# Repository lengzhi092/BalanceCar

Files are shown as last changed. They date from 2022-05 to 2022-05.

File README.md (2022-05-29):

# 双轮平衡车运动控制系统
## 硬件部分
* MCU:STM32F103C8T6
* 姿态采集:MPU6050
* 电机驱动:TB6612FNG

## 开发平台
* STM32CubeMX
* Keil MDK5

## 软件算法
* 卡尔曼滤波
* 串级PID控制
* 速度一阶低通滤波

## 实物展示

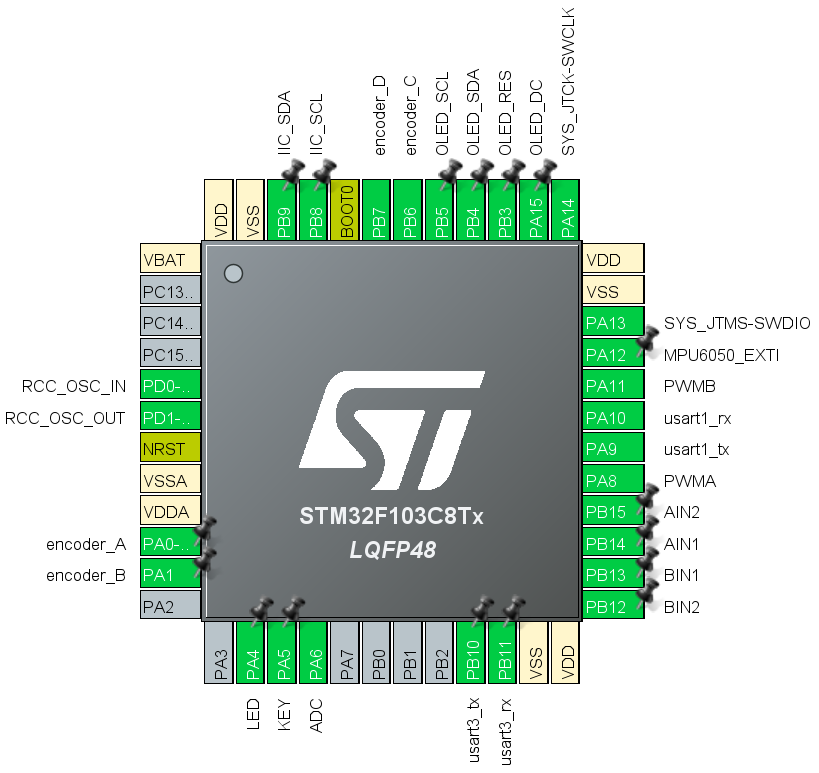
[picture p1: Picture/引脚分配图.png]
引脚分配图

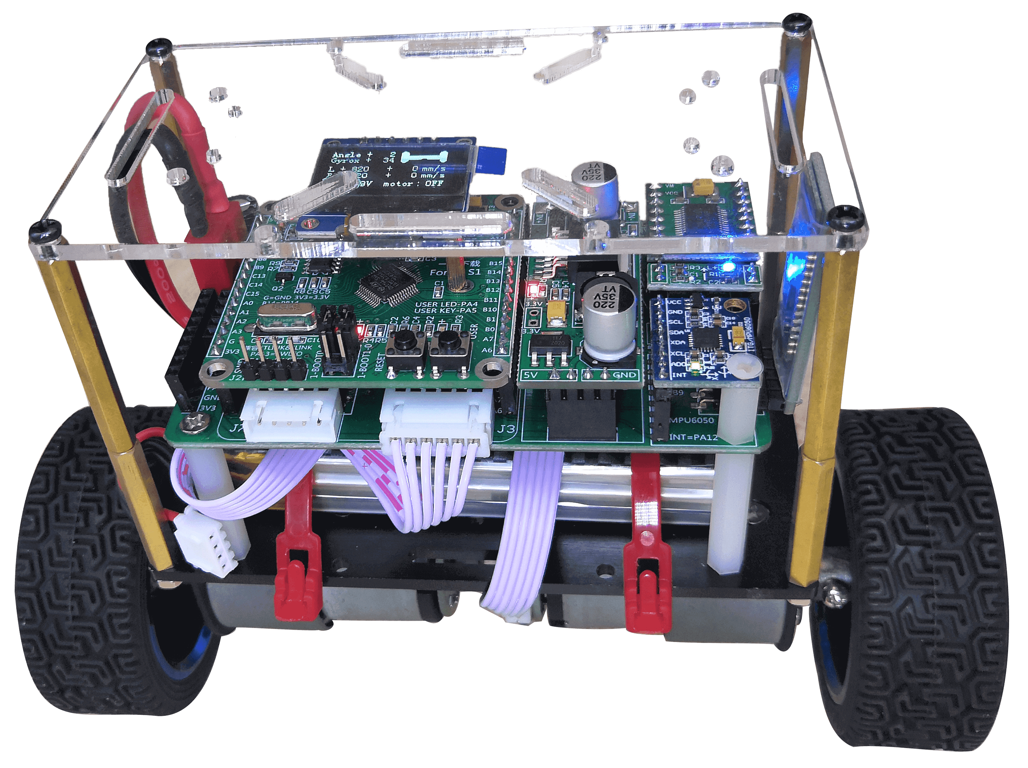
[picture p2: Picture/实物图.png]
车体

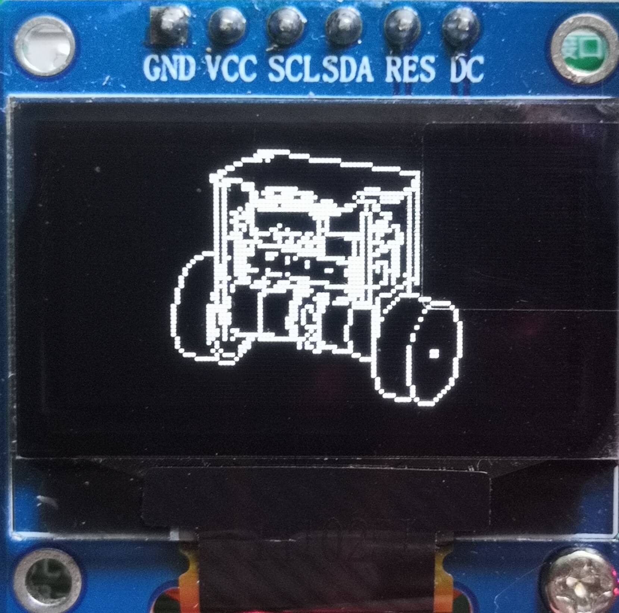
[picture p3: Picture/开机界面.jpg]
开机界面

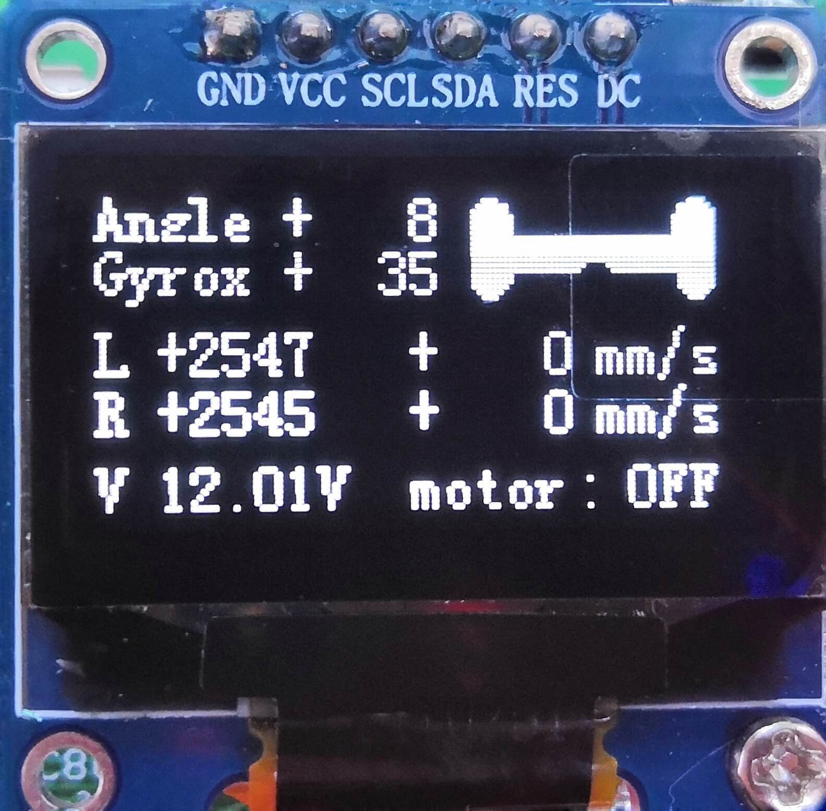
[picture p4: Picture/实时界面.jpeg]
实时界面

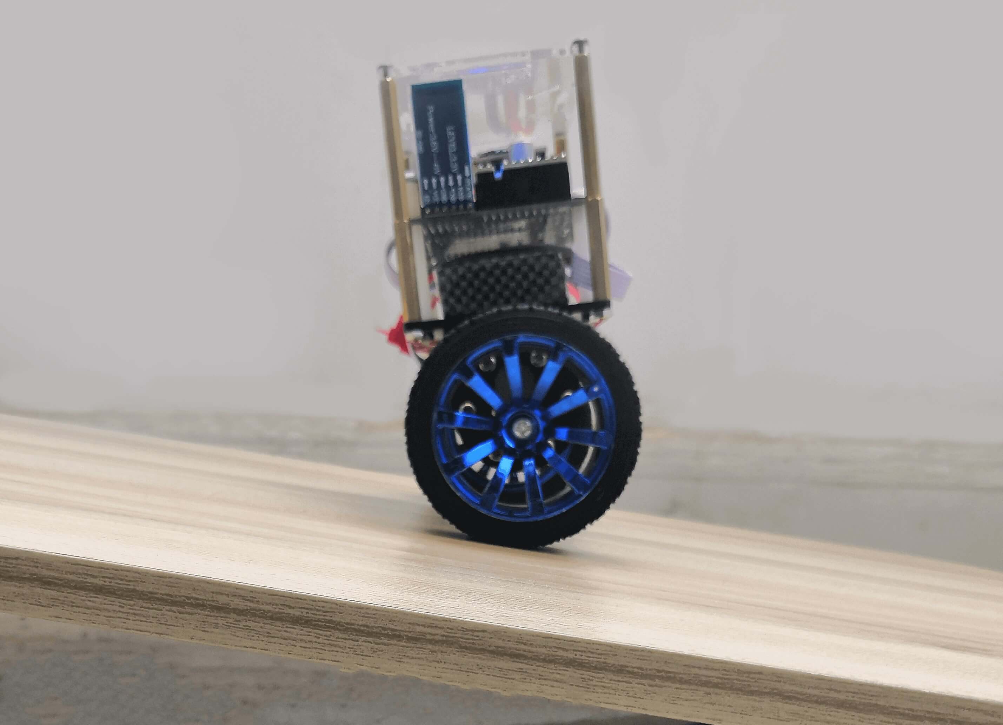
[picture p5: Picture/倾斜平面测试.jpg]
倾斜平面测试


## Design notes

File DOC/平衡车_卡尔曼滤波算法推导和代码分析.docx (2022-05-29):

状态方程： X_k =AX_(k-1) +BU_(k-1) +W_(k-1)

测量方程： Z_k =HX_k -V_k

U_(k-1) ：系统输入量

A、 B：系统参数矩阵

H：观测矩阵

W_(k-1) ：过程噪声矩阵，W~N(0,Q)，Q为过程噪声协方差矩阵

V_k ：观测噪声矩阵，V~N(0,R)，R为观测噪声协方差矩阵

## 一、根据状态方程计算先验估计

X_k^(-) =AX_(k-1) +BU_(k-1)

用陀螺仪计算的角度做估计值： X_k^(-) =Angle_k =Angle_(k-1) +(Gyro_(k-1) -Q_(bias) _(k-1) )dt+W_(k-1)

Q_bias_k =Q_bias_(k-1) +W_(k-1)

Q_bias：陀螺仪静态漂移，是一个变化的量，但是认为预测时现在的漂移跟上一时刻是相同的。

上面两个方程写成矩阵的形式，即得到状态方程：

X_k =[AngleQ_bias]_k =[1, -dt0, 1][AngleQ_bias]_(k-1) +[dt0]Gyro_(k-1) +[W_(k-1) W_(k-1) ]

用加速度分解得到的角度做测量值： Z_k =Accel=Angle_k +R ，写成矩阵形式，得到测量方程：

Z_k =[1, 0][AngleQ_bias]_k +R

将状态方程中的A、B代入上面红色公式，在程序中算出 Angle_k^(-) ，而 Q_bias_k^(-) 预测时认为不变。

## 二、计算先验估计误差协方差矩阵

P_K^(-) =AP_(k-1) A^T +Q

1.先分析过程噪声的协方差矩阵Q

Q=cov[AngleQ_bias]·dt=[cov(Angle,Angle), cov(Q_bias,Angle)cov(Angle,Q_bias), cov(Q_bias,Q_bias)]·dt

协方差知识：衡量两个变量的总体误差

cov(x,y)=1/N∑_(i=1)^n [x_i -E(x)][y_i -E(y)]

当 x、y 相互独立时， cov(x,y)=0

当 x=y 时，协方差又称方差： cov(x,x)=D(x)=1/N∑_(i=1)^n [x_i -E(x)]^2

Angle和Q_bias 相互独立，所以 Q=[D(Angle), 00, D(Q_bias)]·dt

在程序中 D(Angle)=Q_angle=0.001 ， D(Q_(bias) )=Q_gyro=0.003

2.计算先验估计误差协方差矩阵 P_k^(-) ，在程序中 P_k^(-) =[PP_00 , PP_01 PP_10 , PP_11 ]_k^(-) ，代入上方红色公式：

P_k^(-) =[1, -dt0, 1][PP_00 , PP_01 PP_10 , PP_11 ]_(k-1) [1, 0-dt, 1]+[D(Angle), 00, D(Q_bias)]·dt =[PP_00 -PP_10 dt-PP_10 dt+PP_11 (dt)^2 +D(Angle)dt, PP_01 -PP_11 dtPP_10 -PP_11 dt, PP_11 +D(Q_(bias) )dt]_(k-1) =[PP_00 , PP_01 PP_10 , PP_11 ]_(k-1) +[-PP_10 -PP_01 +PP_11 dt+D(Angle), -PP_11 -PP_11 , D(Q_bias)]_(k-1) ·dt

PP_11 (dt)^2 这一项比较小，计算时忽略，然后就是在程序中代公式了，计算出 PP_k^(-) 的四个值。

## 三、计算卡尔曼增益

K_k =P_k^(-) H^T (HP_k^(-) H^T +R)^(-1)

由测量方程知： H=[1, 0] ，先算分母

HP_k^(-) H^T +R=[1, 0][PP_00 , PP_01 PP_10 , PP_11 ]_k^(-) [10]+R=PP_00 _k^(-) +R

整体 K_k =[PP_00 , PP_01 PP_10 , PP_11 ]_k [10]×1/(PP_00 _k^(-) +R)=[PP_00 PP_10 ]×1/(PP_00 _k^(-) +R)=[K_0K_1]

在程序中观测噪声 R=R_angle=0.5 ，代公式计算出 K_0 和 K_1 。

## 四、更新后验估计

X_k =X_K^(-) +K_k (Z_k -HX_K^(-) )

先算括号里的： Z_k -HX_K^(-) =Accel-[1, 0][AngleQ_(bias) ]_k^(-) =Accel-Angle_k^(-)

整体 X_k =[AngleQ_bias]_k =[AngleQ_bias]_k^(-) +[K_1 K_0 ](Accel-Angle_k^(-) )

在程序中算出 Angle_k 和 Q_bias_k

## 五、更新后验估计误差协方差矩阵

P_k =(I-K_k H)P_K^(-)

I 为单位矩阵，代公式 P_k =[[1, 00, 1]-[K_0K_1][1, 0]][PP_00 , PP_01 PP_10 , PP_11 ]_k^(-) = [1-K_0, 0-K_1, 1][PP_00 , PP_01 PP_10 , PP_11 ]_k^(-) =[PP_00 -PP_00 K_0, PP_01 -PP_01 K_0-PP_00 K_1 +PP_10 , PP_01 K_1+PP_11 ]_k^(-)

=[PP_00 , PP_01 PP_10 , PP_11 ]_k^(-) +[-PP_00 K_0, -PP_01 K_0-PP_00 K_1, -PP_01 K_1]_k^(-)

在程序中代公式更新 PP_k 的四个值。

## 程序设计

/**

****************************************************************************

*@brief 获取x轴角度简易卡尔曼滤波

*@param Accel：加速度计获取的角度、Gyro：陀螺仪获取的角速度

*@retval x轴角度

****************************************************************************

*/

float dt=0.005; //每5ms进行一次滤波

float Kalman_Filter_x(float Accel,float Gyro)

{

// static float angle_dot; 角度微分=角速度，本系统用不到

static float angle;

float Q_angle=0.001; // 过程噪声的协方差

float Q_gyro=0.003; //过程噪声的协方差

float R_angle=0.5; //测量噪声的协方差,值越大表示越不信任测量值

char C_0 = 1; //在此程序显得多余

static float Q_bias, Angle_err; //陀螺仪静态漂移

static float PCt_0, PCt_1, E; //E:卡尔曼增益分母

static float K_0, K_1, t_0, t_1;

static float Pdot[4] ={0,0,0,0};

static float PP[2][2] = { { 1, 0 },{ 0, 1 } }; //PP为协方差矩阵Pk-的先验估计值

/************* 角度先验估计 ****************///Xk = A Xk-1 + B Uk-1

angle += (Gyro - Q_bias) * dt;

/************* 先验估计误差协方差 ****************///Pk- =A Pk-1 AT + Q

Pdot[0] = Q_angle - PP[0][1] - PP[1][0];

Pdot[1] = -PP[1][1];

Pdot[2] = -PP[1][1];

Pdot[3] = Q_gyro;

PP[0][0] += Pdot[0] * dt;

PP[0][1] += Pdot[1] * dt;

PP[1][0] += Pdot[2] * dt;

PP[1][1] += Pdot[3] * dt;

/************* 计算卡尔曼增益 ****************///Kk = Pk- HT / (H Pk- HT + R)

PCt_0 = C_0 * PP[0][0]; //显得多余

PCt_1 = C_0 * PP[1][0]; //显得多余

E = R_angle + C_0 * PCt_0; //求卡尔曼增益分母，直接E = R_angle + PP[0][0]就行

K_0 = PCt_0 / E; //计算卡尔曼增益，为两行一列的矩阵

K_1 = PCt_1 / E;

/************* 角度后验估计 ****************///Xk = Xk- + Kk (Zk - H Xk-)

Angle_err = Accel - angle; //(Zk - H Xk-)

angle += K_0 * Angle_err; //后验估计

Q_bias += K_1 * Angle_err; //后验估计

// angle_dot = Gyro - Q_bias; //输出值(后验估计)的微分=角速度

/************* 更新协方差矩阵 ****************///Pk = (I - Kk H) Pk-

t_0 = PCt_0;

t_1 = C_0 * PP[0][1];

PP[0][0] -= K_0 * t_0; //后验估计误差协方差

PP[0][1] -= K_0 * t_1;

PP[1][0] -= K_1 * t_0;

PP[1][1] -= K_1 * t_1;

return angle;

}

WRITE BY LENGZHI

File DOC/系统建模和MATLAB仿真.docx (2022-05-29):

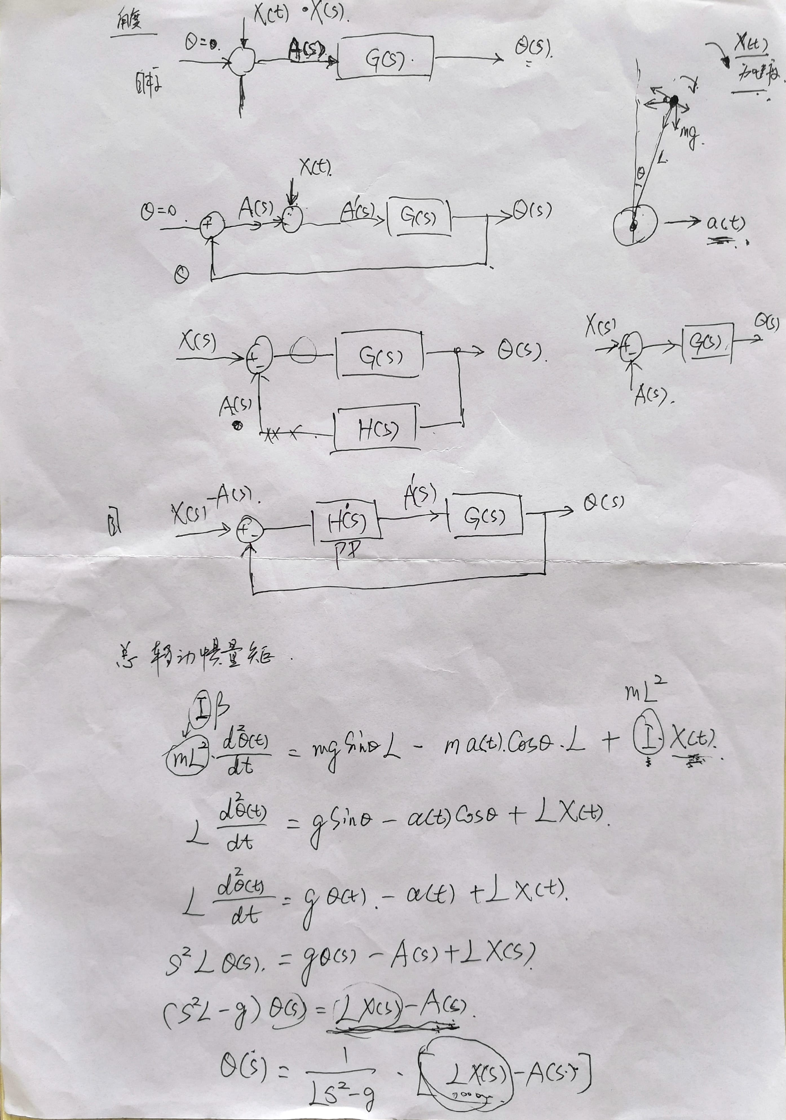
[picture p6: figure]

# 传递函数建立

模型分析主要有两种方法，一种是拉格朗日(Lagrange)分析法，该方法引用广义坐标，降低了分析对象的难度，但是理解上较为困难。另一种是牛顿欧拉方程法(Newton-Euler)，它的优点是根据我们学过的牛顿三大定律进行分析，模型表达式也代表确定的物理含义，建模过程更加通俗易懂，并且其计算相对简便，对于后期的控制算法设计也有一定的简化。

双轮平衡车模型类似一级倒立摆，我们将并行的双轮设定在一个点上，同时忽略其转向控制，有倒下趋势的倒立摆为非惯性系统，，切换参照物，不再以地面为参照，以车轮中线为原点O，向前为x轴正方向，竖直向上为y轴正方向，建立二维的平衡车的倒立摆模型

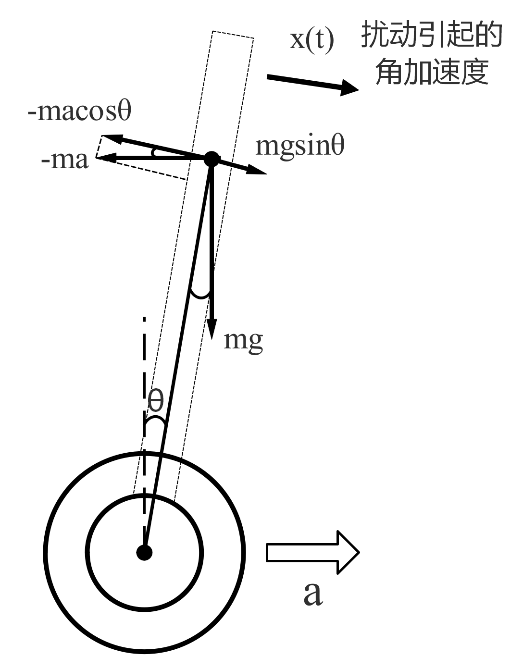
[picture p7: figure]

在非惯性坐标系下，对模型进行受力分析，设小车质量为m，车轮向前加速后产生一个向后的“惯性力”，提供车体回复力的一部分，它的大小和车轮向前施加的力相等，与车轮加速的方向相反

F_惯 =-macosθ

假设平衡车的重心高度为L，转动惯量矩 =FL=Ιβ ，Ι =mL^2 ，β为角加速度

系统转动惯量矩平衡方程可以表示为:

mL^2 (ⅆ^2 θ(t))/(ⅆt^2)=mgsin[θ(t)]L-ma(t)cos[θ(t)]L+mL^2 x(t)

线性化处理，当θ很小时 sinθ=θ , cosθ=1 ，可以将运动微分方程简化为

L(ⅆ^2 θ(t))/(ⅆt^2)=gθ(t)-a(t)+Lx(t)

以 Lx(t) 和车轮的加速度 a(t) 之差为输入, 倾角 θ(t) 为输出的开环传递函数为：

H(s)=(Θ(s))/(LX(s)-A(s))=1/(Ls^2 -g)

此时平衡车系统有两个闭环极点： s_p =±√((g-1)/L) ，分别位于位于s平面的左半平面和右半平面，根据 Nyquist 判据判断出该系统不稳定，

引入PD控制，新的系统开环传递函数为：

H(s)=(Θ(s))/(LX(s)-A(s))=(k_p +k_d s)/(Ls^2 -g)

对应的闭环传递函数为：

H(s)=(Θ(s))/(LX(s)-A(s))=(k_p +k_d s)/(Ls^2 +k_d s+k_p -g)

这时系统有两闭环极点， S_P =(-k_d ±√(k_d^2 +4L(k_p -g)))/(-2L) 根据Nyquist判据,要使系统稳定，只需两极点都处在s平面的左半平面，即要求 k_p >g ， k_d >0

1.在matlab中进行系统建模，在不加入控制量的情况下，输出其零输入响应图，印证了此系统为自然不稳定体的结论。

2.在模型中增设控制量参数，通过冲激响应验证其在控制下能够保持平衡稳定。

3.利用连续的阶跃响应验证了在加入持续的控制量参数情况下，系统会随控制量的增加调整系统的姿态，并且在持续加入控制量时维持此种姿态。

通过以上仿真实验，验证了此系统下的动态平衡，同时也为后续的软件设计控制算法及其控制量参数调整的方向上给予了一定的指导经验。

# Simulink模型搭建

## Transfer function 传递函数

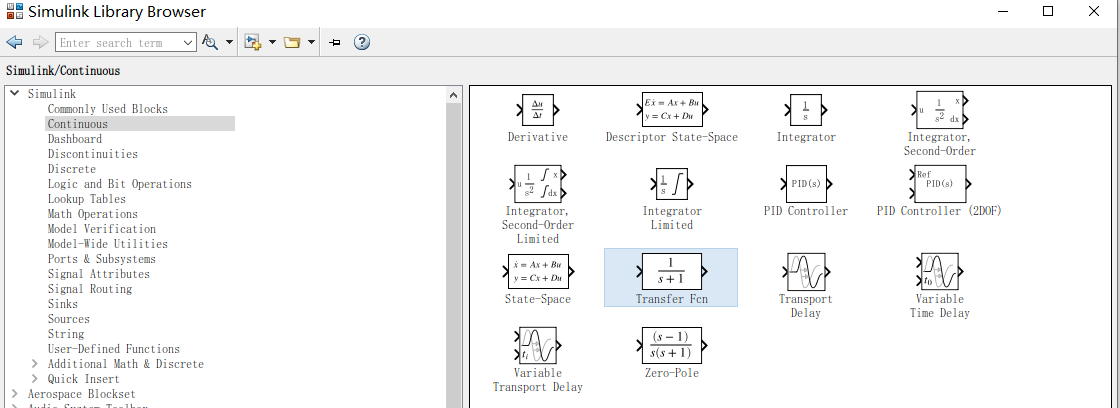
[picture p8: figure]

## Constant 常数

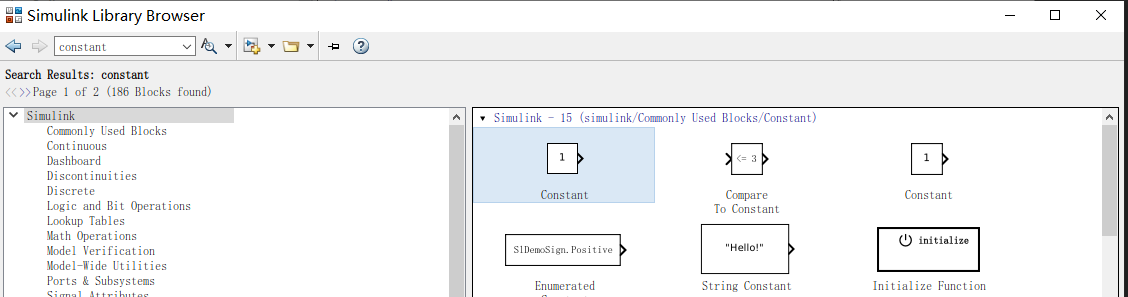
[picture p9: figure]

## Sum

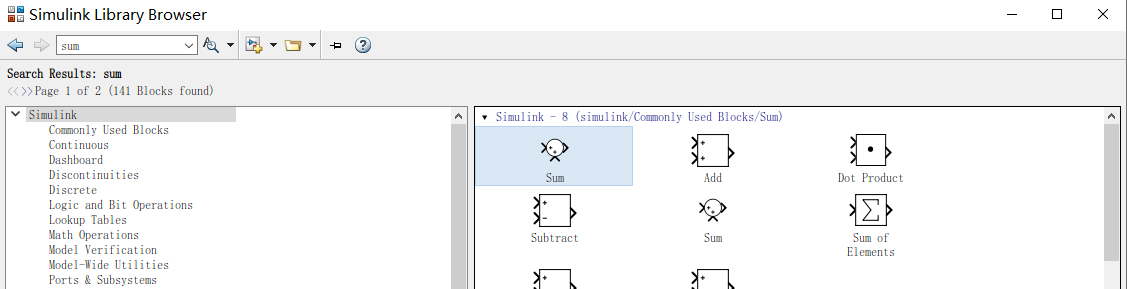
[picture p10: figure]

## pid

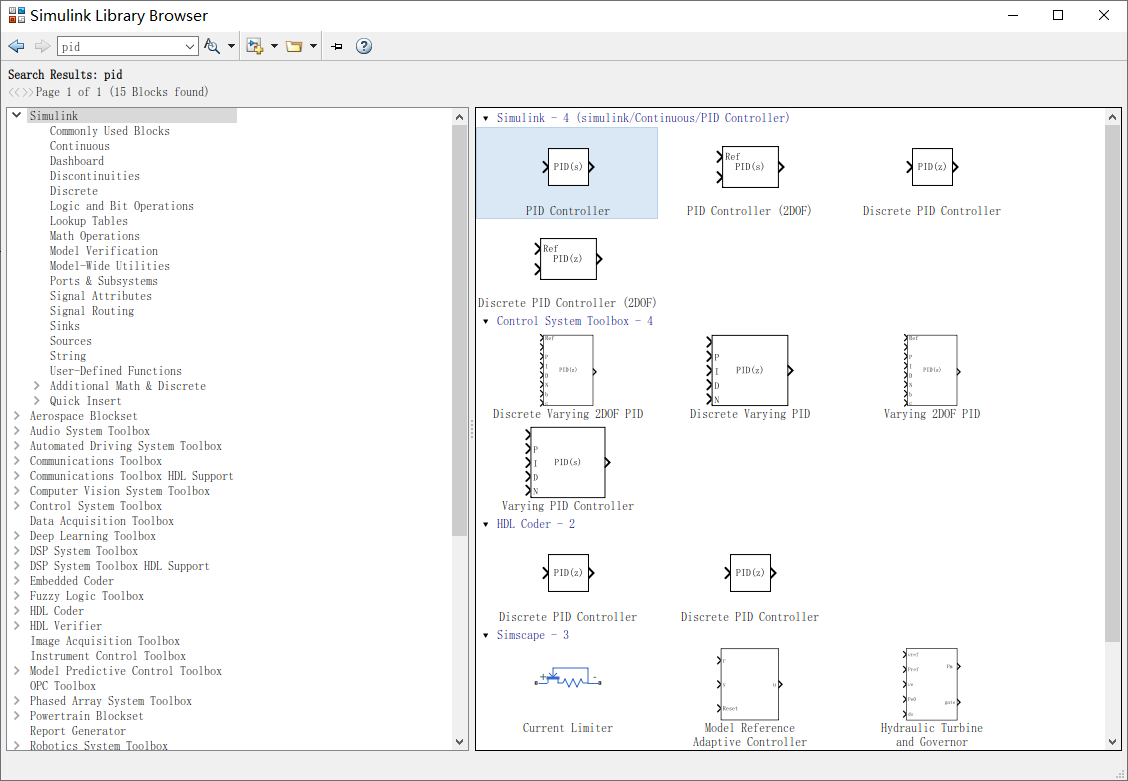
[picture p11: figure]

## Scope

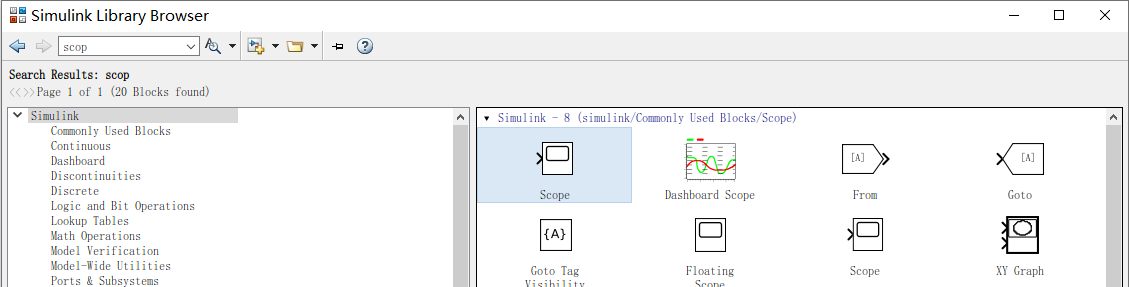
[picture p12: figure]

# 最终模型

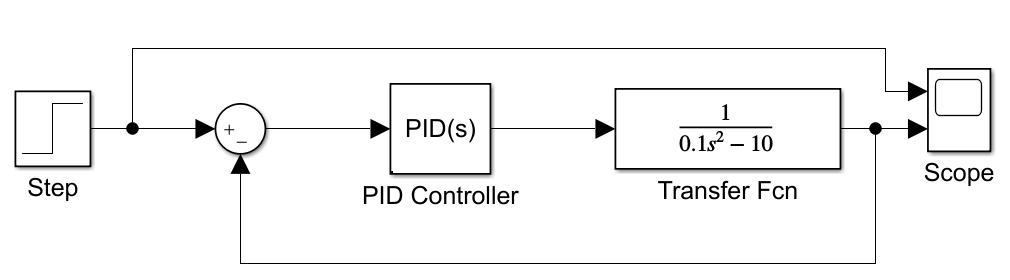
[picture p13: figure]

# 错误调参记录

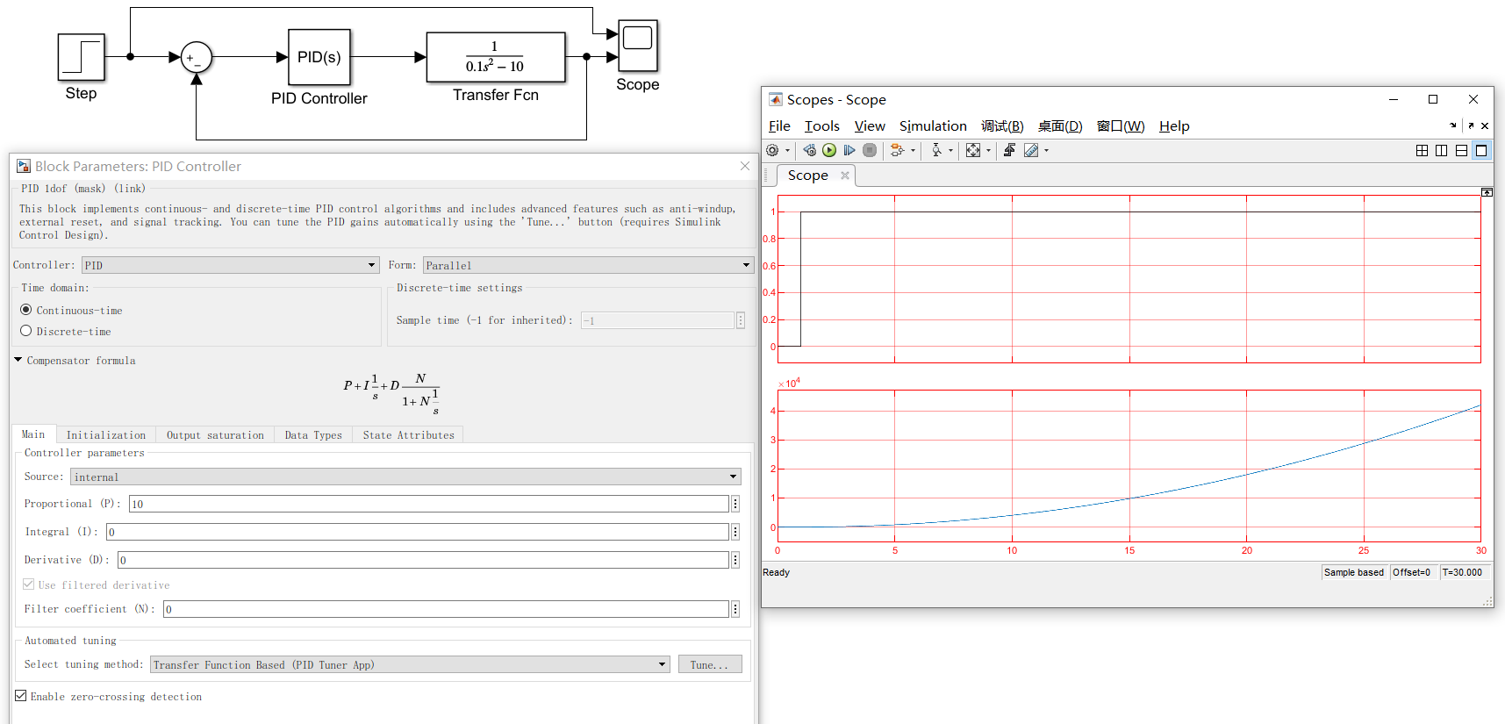
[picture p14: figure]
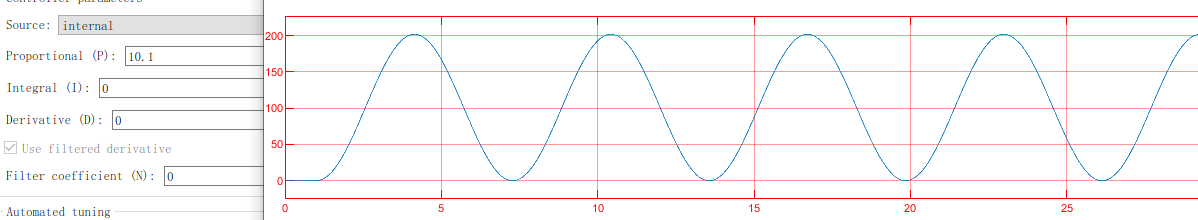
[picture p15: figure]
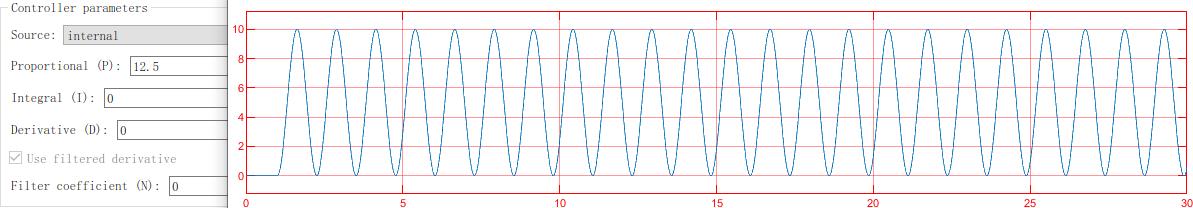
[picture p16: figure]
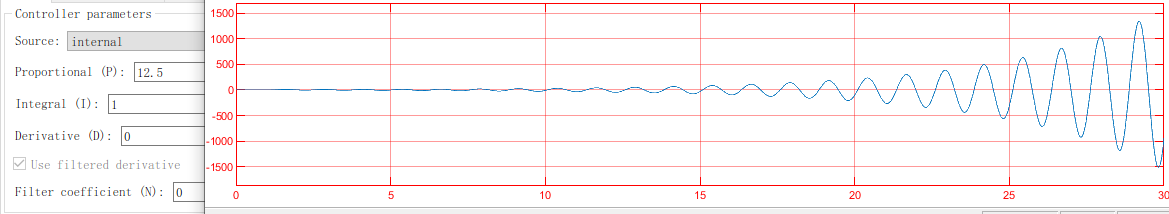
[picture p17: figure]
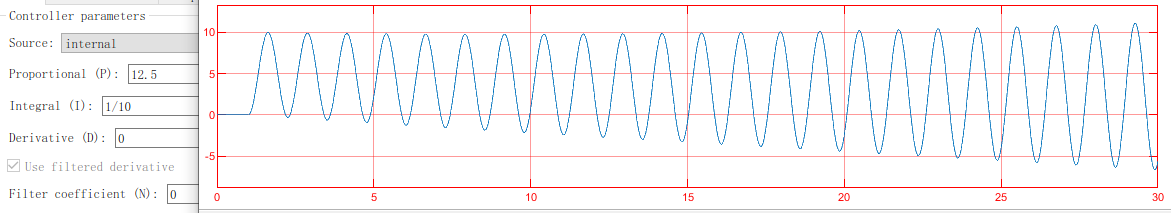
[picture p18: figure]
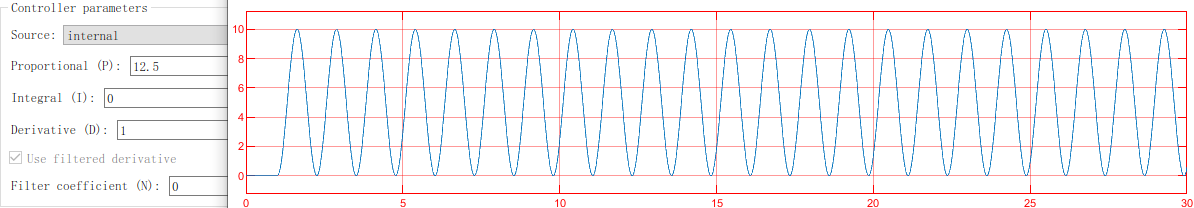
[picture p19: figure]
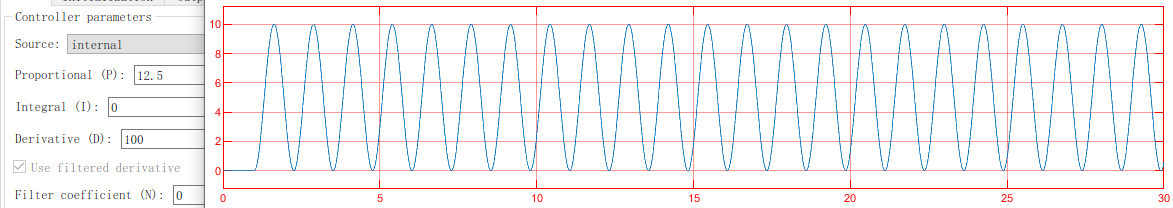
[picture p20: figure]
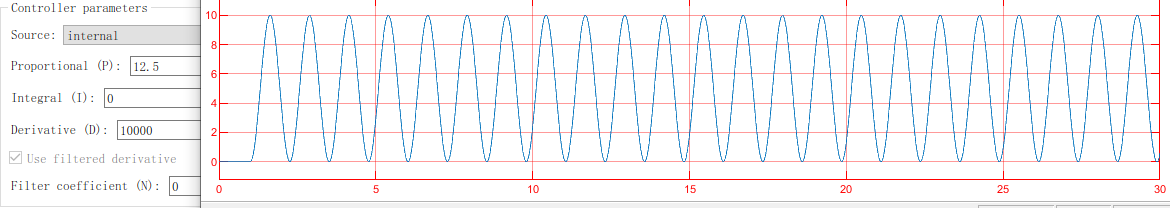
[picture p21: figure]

# 老师指导结果

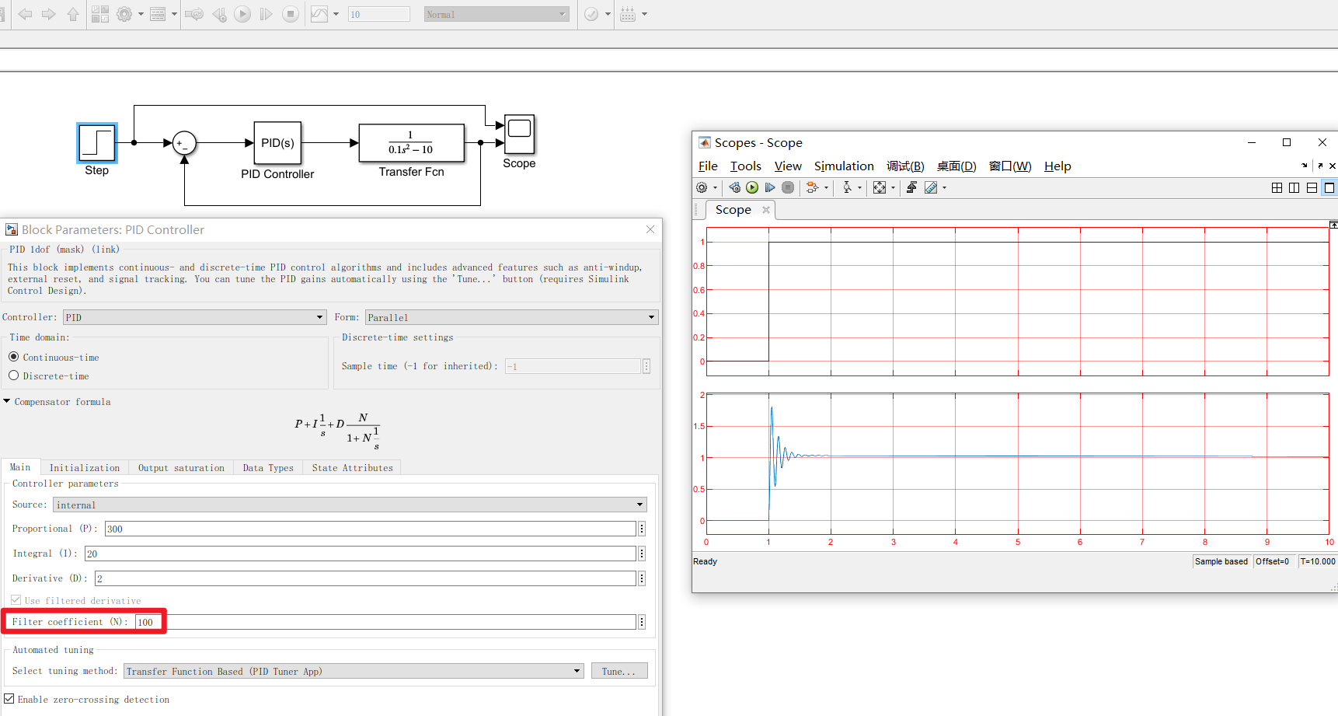
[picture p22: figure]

原因总结：调参不仅要调PID，根据实际情况，还要调filter coefficient（上图红框），因为误差e变化微弱的时候，如果D过大会产生过大的修正量，导致震动不但不减小反而扩大，滤波器的作用就是滤除高频修正

# 再次自主调参记录

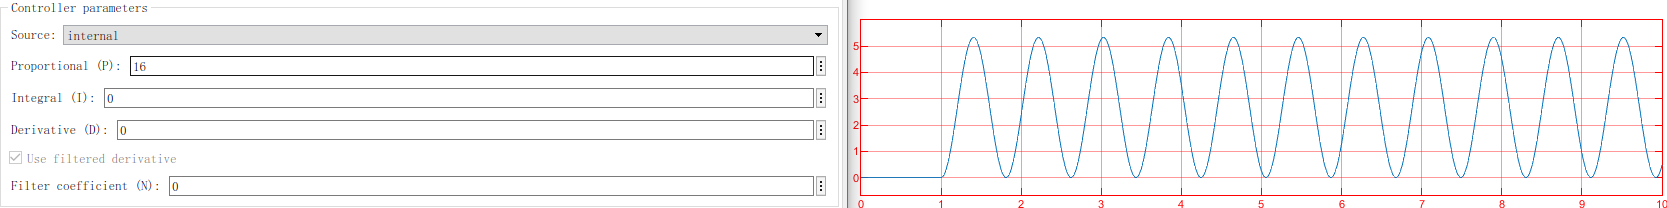
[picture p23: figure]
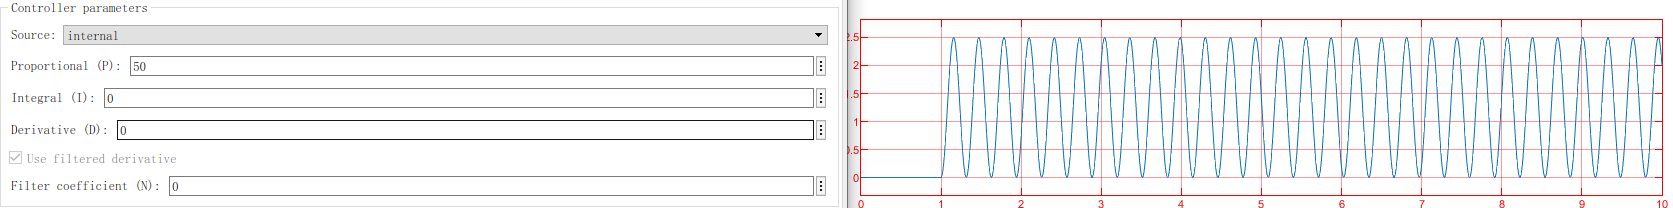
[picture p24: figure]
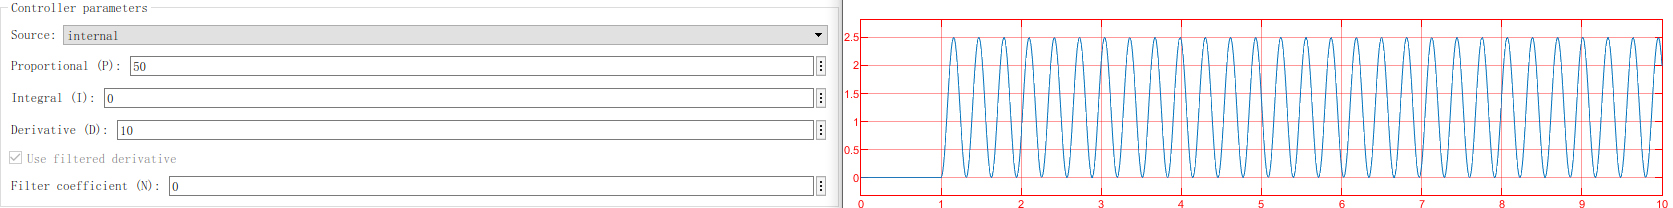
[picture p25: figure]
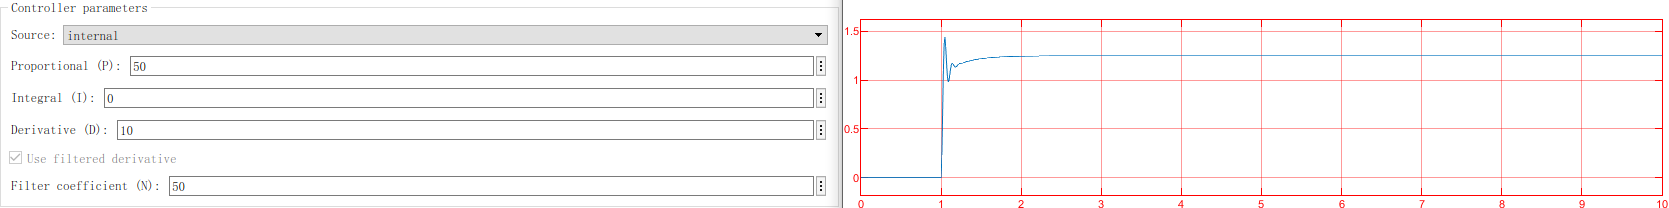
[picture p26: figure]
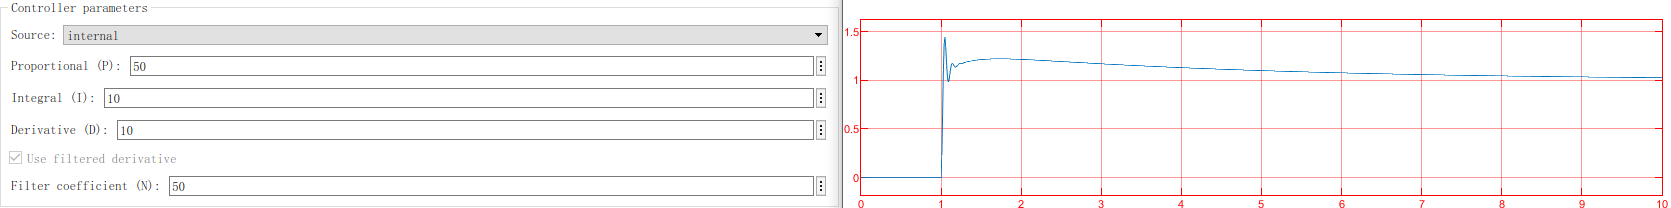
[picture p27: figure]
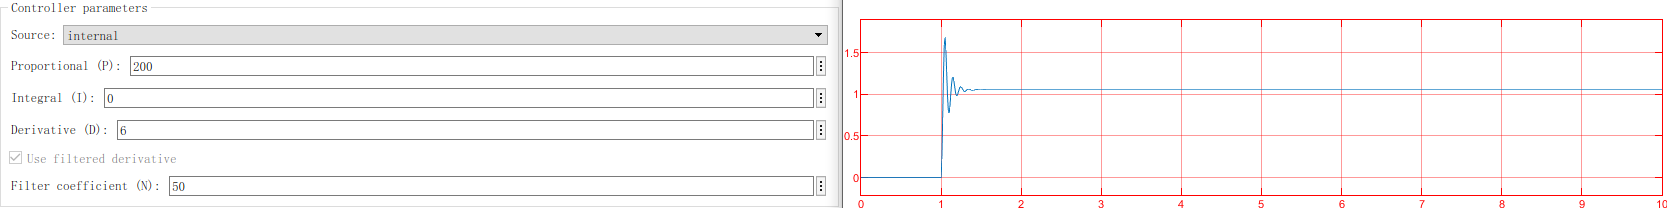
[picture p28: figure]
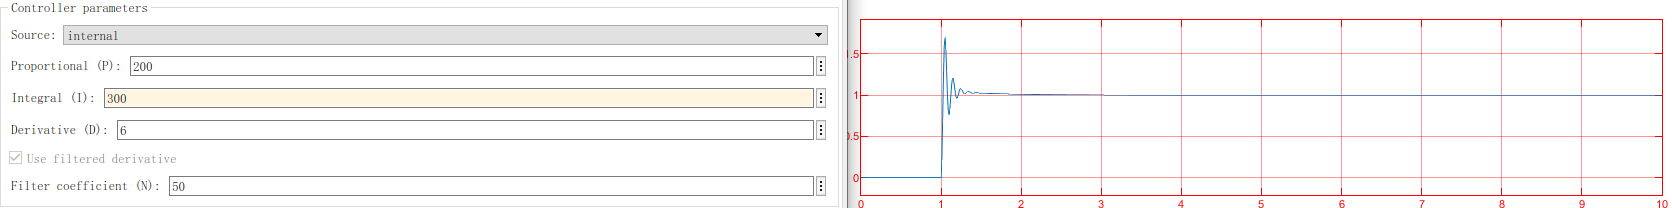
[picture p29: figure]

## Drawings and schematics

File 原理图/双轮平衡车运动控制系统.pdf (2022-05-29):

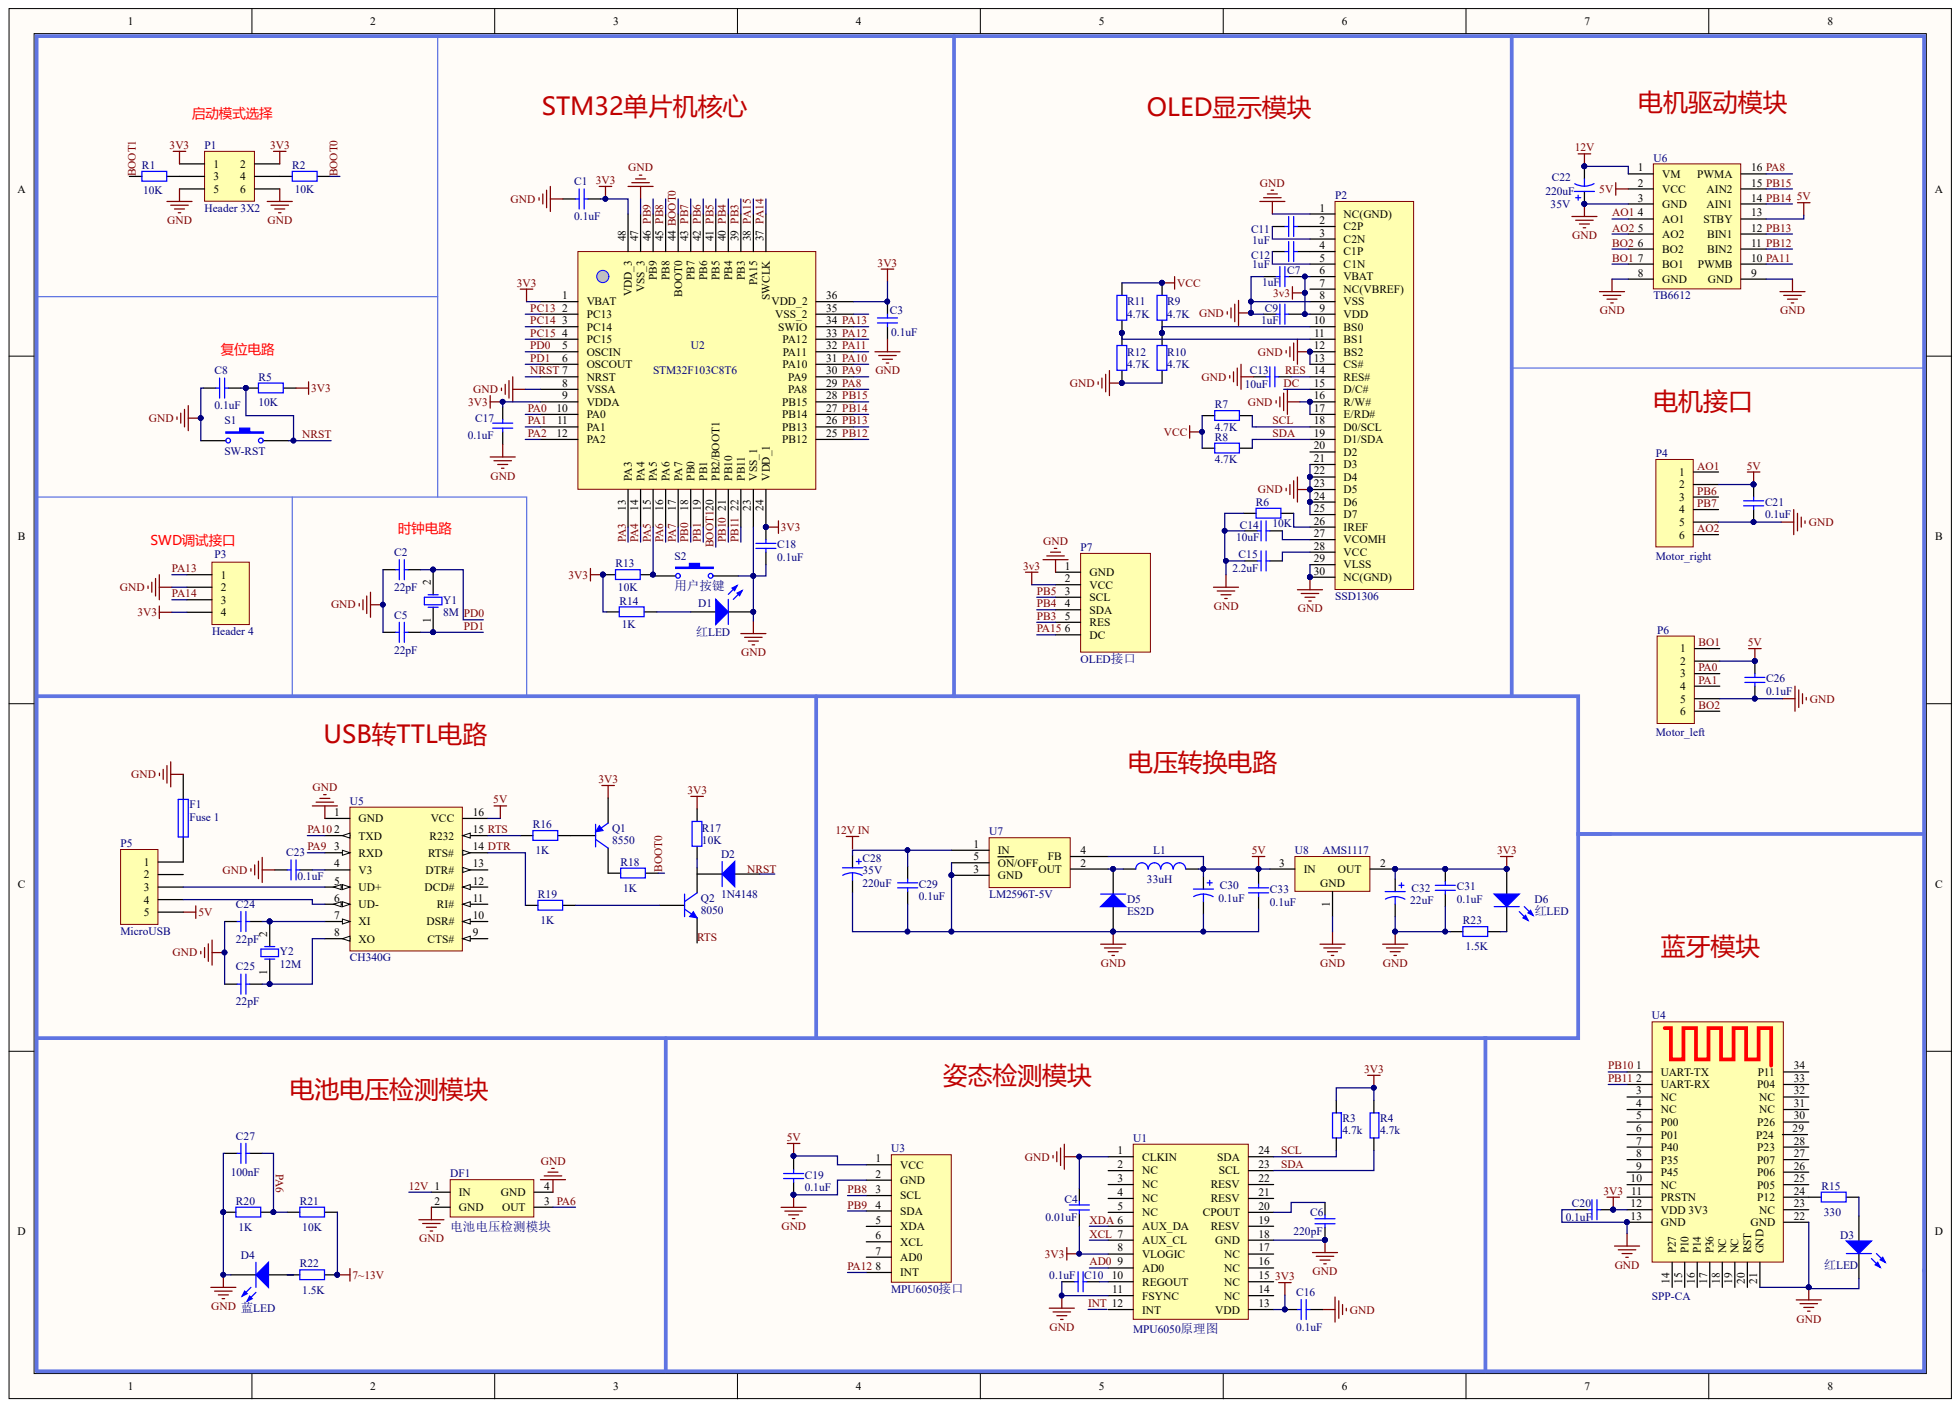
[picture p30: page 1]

GND 21 GND 22 NC 23 P12 24 P05 25 P06 26 P07 27 P23 28 P24 29 P26 30 NC 31 NC 32 P04 33 P11 34

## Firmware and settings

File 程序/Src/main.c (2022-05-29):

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
/* Includes ------------------------------------------------------------------*/
#include "main.h"
#include "adc.h"
#include "tim.h"
#include "usart.h"
#include "gpio.h"

/* USER CODE BEGIN Includes */
#include "sys.h"
/* USER CODE END Includes */

/* USER CODE BEGIN PTD */
float Angle_Balance,Gyro_Balance,Gyro_Turn; //平衡倾角 平衡陀螺仪 转向陀螺仪
float Velocity_Left,Velocity_Right; //车轮速度(mm/s)
int Temperature;    //温度变量
float Acceleration_Z;   //Z轴加速度计  
int Voltage;    //电池电压采样相关的变量
volatile u8 delay_flag,delay_50;    //提供延时的变量
u8 Flag_Stop=1,Flag_Show=0; //电机停止标志位和显示标志位  默认停止 OLED显示打开
int Motor_Left,Motor_Right; //电机PWM变量
u8 Flag_front,Flag_back,Flag_Left,Flag_Right,Flag_velocity=2; //蓝牙遥控相关的变量
float Balance_Kp=28000,Balance_Kd=114,Velocity_Kp=38000,Velocity_Ki=190,Turn_Kp=4400,Turn_Kd=55; //PID参数（放大100倍）
u8 PID_Send;    //调参相关变量

/* USER CODE END PTD */


void SystemClock_Config(void);
/**
  * @brief  The application entry point.
  * @retval int
  */
int main(void)
{
  /* MCU Configuration--------------------------------------------------------*/

  /* Reset of all peripherals, Initializes the Flash interface and the Systick. */
  HAL_Init();

  /* Configure the system clock */
  SystemClock_Config();

  /* Initialize all configured peripherals */
  MX_GPIO_Init();
  MX_ADC1_Init();
  MX_TIM1_Init();
  MX_TIM2_Init();
  MX_TIM3_Init();
  MX_TIM4_Init();
  MX_USART1_UART_Init();
  MX_USART3_UART_Init();
  /* USER CODE BEGIN 2 */
    delay_init();
    OLED_Init();
    MPU6050_initialize();
    DMP_Init();
    HAL_NVIC_EnableIRQ(EXTI15_10_IRQn); //开启引脚外部中断
    StartingDisplay();
  /* USER CODE END 2 */

  /* Infinite loop */
  /* USER CODE BEGIN WHILE */
while (1)
{
    if(Flag_Show==0)    //使用MiniBalance APP和OLED显示屏
    {
        APP_Show(); //发送数据给APP
        Oled_Show();    //显示屏打开
    }
    else    //使用MiniBalance上位机 上位机使用的时候需要严格的时序，故此时关闭app监控部分和OLED显示屏
    {
        DataScope();   //开启MiniBalance上位机，长按按键即可
    }
    delay_flag=1;
    delay_50=0;
    while(delay_flag)   ;  //示波器需要50ms	高精度延时，delay函数不满足要求，故使用MPU6050中断提供50ms延时
}
    /* USER CODE END WHILE */

}

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


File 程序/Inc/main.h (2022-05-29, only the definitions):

#define encoder_A_Pin GPIO_PIN_0
#define encoder_A_GPIO_Port GPIOA
#define encoder_B_Pin GPIO_PIN_1
#define encoder_B_GPIO_Port GPIOA
#define LED_Pin GPIO_PIN_4
#define LED_GPIO_Port GPIOA
#define KEY_Pin GPIO_PIN_5
#define KEY_GPIO_Port GPIOA
#define ADC_Pin GPIO_PIN_6
#define ADC_GPIO_Port GPIOA
#define usart3_tx_Pin GPIO_PIN_10
#define usart3_tx_GPIO_Port GPIOB
#define usart3_rx_Pin GPIO_PIN_11
#define usart3_rx_GPIO_Port GPIOB
#define BIN2_Pin GPIO_PIN_12
#define BIN2_GPIO_Port GPIOB
#define BIN1_Pin GPIO_PIN_13
#define BIN1_GPIO_Port GPIOB
#define AIN1_Pin GPIO_PIN_14
#define AIN1_GPIO_Port GPIOB
#define AIN2_Pin GPIO_PIN_15
#define AIN2_GPIO_Port GPIOB
#define PWMA_Pin GPIO_PIN_8
#define PWMA_GPIO_Port GPIOA
#define usart1_tx_Pin GPIO_PIN_9
#define usart1_tx_GPIO_Port GPIOA
#define usart1_rx_Pin GPIO_PIN_10
#define usart1_rx_GPIO_Port GPIOA
#define PWMB_Pin GPIO_PIN_11
#define PWMB_GPIO_Port GPIOA
#define MPU6050_EXTI_Pin GPIO_PIN_12
#define MPU6050_EXTI_GPIO_Port GPIOA
#define MPU6050_EXTI_EXTI_IRQn EXTI15_10_IRQn
#define OLED_DC_Pin GPIO_PIN_15
#define OLED_DC_GPIO_Port GPIOA
#define OLED_RES_Pin GPIO_PIN_3
#define OLED_RES_GPIO_Port GPIOB
#define OLED_SDA_Pin GPIO_PIN_4
#define OLED_SDA_GPIO_Port GPIOB
#define OLED_SCL_Pin GPIO_PIN_5
#define OLED_SCL_GPIO_Port GPIOB
#define encoder_C_Pin GPIO_PIN_6
#define encoder_C_GPIO_Port GPIOB
#define encoder_D_Pin GPIO_PIN_7
#define encoder_D_GPIO_Port GPIOB
#define IIC_SCL_Pin GPIO_PIN_8
#define IIC_SCL_GPIO_Port GPIOB
#define IIC_SDA_Pin GPIO_PIN_9
#define IIC_SDA_GPIO_Port GPIOB

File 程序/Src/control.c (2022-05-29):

/**
    ****************************************************************************
    *@file       control.c
    *@auther     wxf
    *@version    V1.0.0
    *@date       2022.3
    *@brief      控制的核心部分
    ****************************************************************************
    *@attension  
    *
    ****************************************************************************
    */
#include "control.h"
/**
    ****************************************************************************
    *@brief      外部中断回调函数
    *@param      5ms外部中断由MPU6050的INT（PA12）引脚触发,严格保证采样和数据处理的时间同步
    *@retval     0
    ****************************************************************************
    */
int HAL_GPIO_EXTI_Callback(uint16_t GPIO_Pin)
{
	static int Voltage_Temp,Voltage_Count,Voltage_All;  //电压测量相关变量
	static u8 Flag_Target;  //控制函数相关变量，提供10ms基准 
	int Encoder_Left,Encoder_Right;    //左右编码器的脉冲计数
	int Balance_Pwm,Velocity_Pwm,Turn_Pwm;  //平衡环PWM变量，速度环PWM变量，转向环PWM变量
	if(GPIO_Pin==MPU6050_EXTI_Pin)
	{  
        Flag_Target=!Flag_Target;
        Get_Angle();    //更新姿态，5ms一次，更高的采样频率可以改善卡尔曼滤波和互补滤波的效果
        Encoder_Left=-Read_Encoder(2);  //读取左轮编码器的值，前进为正，后退为负
        Encoder_Right=-Read_Encoder(4); //读取右轮编码器的值，前进为正，后退为负
                                    //左轮A相接TIM2_CH1,右轮A相接TIM4_CH2,故这里两个编码器的极性相同
        Get_Velocity_Form_Encoder(Encoder_Left,Encoder_Right);    //编码器读数转速度（mm/s）
        if(Flag_Target==1)  //10ms控制一次
        {
            Voltage_Temp=Get_battery_volt();    //读取电池电压		
            Voltage_Count++;    //平均值计数器
            Voltage_All+=Voltage_Temp;    //多次采样累积
            if(Voltage_Count==100) Voltage=Voltage_All/100,Voltage_All=0,Voltage_Count=0;   //求平均值		
            return 0;
        }
    	Key();    //按键扫描处理 单击双击可以改变小车运行状态
    	Balance_Pwm=Balance(Angle_Balance,Gyro_Balance);    //平衡PID控制 Gyro_Balance平衡角速度极性：前倾为正，后倾为负
    	Velocity_Pwm=Velocity(Encoder_Left,Encoder_Right);  //速度环PID控制	记住，速度反馈是正反馈，就是小车快的时候要慢下来就需要再跑快一点
    	Turn_Pwm=Turn(Gyro_Turn);    //转向环PID控制

    	Motor_Left=Balance_Pwm+Velocity_Pwm+Turn_Pwm;   //计算左轮电机最终PWM
    	Motor_Right=Balance_Pwm+Velocity_Pwm-Turn_Pwm;  //计算右轮电机最终PWM
    													//PWM值正数使小车前进，负数使小车后退
    	Motor_Left=PWM_Limit(Motor_Left,6900,-6900);
    	Motor_Right=PWM_Limit(Motor_Right,6900,-6900);  //PWM限幅
    	if(Turn_Off(Angle_Balance,Voltage)==0)  //如果不存在异常
    		Set_Pwm(Motor_Left,Motor_Right);    //赋值给PWM寄存器  
	}
  	return 0;
}
/**
    ****************************************************************************
    *@brief      直立PD控制
    *@param      Angle:角度；Gyro：角速度
    *@retval     balance：直立控制PWM
    ****************************************************************************
    */
int Balance(float Angle,float Gyro)
{
    float Angle_bias,Gyro_bias;
    int balance;
    Angle_bias=Middle_angle-Angle;  //求出平衡的角度中值 和机械相关
    Gyro_bias=0-Gyro;
    balance=-Balance_Kp/100*Angle_bias-Gyro_bias*Balance_Kd/100;    //计算平衡控制的电机PWM：PD控制：kp是P系数，kd是D系数 
    return balance;
}
/**
    ****************************************************************************
    *@brief      速度控制PWM
    *@param      encoder_left：左轮编码器读数；encoder_right：右轮编码器读数
    *@retval     速度控制PWM
    ****************************************************************************
    *///修改前进后退速度，请修改Target_Velocity
int Velocity(int encoder_left,int encoder_right)
{
    static float velocity,Encoder_Latest,Encoder_bias,Movement;
    static float Encoder_Integral,Target_Velocity = 35;
	  //================遥控前进后退部分====================//
    if(Flag_front==1)   Movement=Target_Velocity/Flag_velocity; //收到前进信号
    else if(Flag_back==1)   Movement=-Target_Velocity/Flag_velocity;    //收到后退信号
    else    Movement=0;
   //================速度PI控制器=====================//	
    Encoder_Latest =0-(encoder_left+encoder_right);  //获取最新速度偏差=目标速度（此处为零）-测量速度（左右编码器之和） 
    Encoder_bias *= 0.86;   //一阶低通滤波器时域表达式为: y(n)= Kx(n) + (1-K)y(n-1) 取k=0.14   
    Encoder_bias += Encoder_Latest*0.14; //一阶低通滤波器，减缓速度变化 
    Encoder_Integral +=Encoder_bias;    //积分出位移 积分时间：5ms
    Encoder_Integral=Encoder_Integral+Movement; //接收遥控器数据，控制前进后退
    if(Encoder_Integral>10000)  Encoder_Integral=10000; //积分限幅
    if(Encoder_Integral<-10000) Encoder_Integral=-10000;    //积分限幅	
    velocity=-Encoder_bias*Velocity_Kp/100-Encoder_Integral*Velocity_Ki/100;    //速度PI控制
    if(Turn_Off(Angle_Balance,Voltage)==1||Flag_Stop==1)    Encoder_Integral=0;    //电机关闭后清除积分
	return velocity;
}
/**
    ****************************************************************************
    *@brief      转向控制
    *@param      Z轴陀螺仪
    *@retval     转向控制PWM
    ****************************************************************************
    */
int Turn(float gyro)
{
    static float Turn_Target,turn,Turn_Amplitude=54;
    float Kp=Turn_Kp,Kd; //修改转向速度，请修改Turn_Amplitude即可
    //===================遥控左右旋转部分=================//
    if(1==Flag_Left)   Turn_Target=-Turn_Amplitude/Flag_velocity;
    else if(1==Flag_Right) Turn_Target=Turn_Amplitude/Flag_velocity;
    else Turn_Target=0;
    
    if(1==Flag_front||1==Flag_back) Kd=Turn_Kd;
    else Kd=0;    //转向的时候取消陀螺仪的纠正 有点模糊PID的思想
    //===================转向PD控制器=================//
    turn=Turn_Target*Kp/100+gyro*Kd/100; //结合Z轴陀螺仪进行PD控制
    return turn;   //转向环PWM右转为正，左转为负
}
/**
    ****************************************************************************
    *@brief      绝对值函数
    *@param      a：需要计算绝对值的数
    *@retval     u32
    ****************************************************************************
    */
u32 myabs(int a)
{
	int temp;
	if(a<0)    temp=-a;  
	else    temp=a;
	return temp;
}
/**
    ****************************************************************************
    *@brief      赋值给PWM寄存器
    *@param      左轮PWM、右轮PWM
    *@retval     无
    ****************************************************************************
    */
void Set_Pwm(int motor_left,int motor_right)
{
    if(motor_left>0)    BIN1=1, BIN2=0; //前进 
	else    BIN1=0, BIN2=1; //后退
        PWMB=myabs(motor_left);	
    if(motor_right>0)    AIN2=1,AIN1=0; //前进
    else    AIN2=0, AIN1=1; //后退
        PWMA=myabs(motor_right);
}
/**
    ****************************************************************************
    *@brief      限制PWM幅值
    *@param      IN：输入参数  max：限幅最大值  min：限幅最小值
    *@retval     限幅后的值
    ****************************************************************************
    */
int PWM_Limit(int IN,int max,int min)
{
	int OUT = IN;
	if(OUT>max)    OUT = max;
	if(OUT<min)    OUT = min;
	return OUT;
}
/**
    ****************************************************************************
    *@brief      异常关闭电机
    *@param      angle：小车倾角；voltage：电压
    *@retval     1：异常  0：正常
    ****************************************************************************
    */
u8 Turn_Off(float angle, int voltage)
{
	u8 temp;
	if(angle<-40||angle>40||1==Flag_Stop||voltage<1110)//电池电压低于11.1V关闭电机
	{   //倾角大于40度关闭电机
		temp=1;
		AIN1=0; AIN2=0; BIN1=0; BIN2=0;
	}
	else
		temp=0;
	return temp;			
}

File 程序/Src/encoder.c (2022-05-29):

/**
    ****************************************************************************
    *@file       encoder.c
    *@auther     wxf
    *@version    V1.0.0
    *@date       2022.3.20
    *@brief      编码器驱动
    ****************************************************************************
    *@attension  
    *
    ****************************************************************************
    */
#include "encoder.h"

/**
    ****************************************************************************
    *@brief      单位时间读取编码器计数
    *@param      TIMX：定时器
    *@retval     速度值
    ****************************************************************************
    */
int Read_Encoder(u8 TIMX)
{
    int Encoder_TIM;    
    switch(TIMX)
    {
        case 2:  Encoder_TIM= (short)TIM2 -> CNT;  TIM2 -> CNT=0;break;   //short：强制类型转换
        case 3:  Encoder_TIM= (short)TIM3 -> CNT;  TIM3 -> CNT=0;break;	
        case 4:  Encoder_TIM= (short)TIM4 -> CNT;  TIM4 -> CNT=0;break;	
        default: Encoder_TIM=0;
    }
    return Encoder_TIM;
}
/**
    ****************************************************************************
    *@brief      编码器读数转换为速度（mm/s）
    *@param      encoder_left：左轮编码器读数，encoder_right：右轮编码器读数
    *@retval     无
    ****************************************************************************
    */
void Get_Velocity_Form_Encoder(int encoder_left,int encoder_right)
{ 	
	float Rotation_Speed_L,Rotation_Speed_R;    //电机转速=编码器读数（5ms每次）*读取频率/倍频数/减速比/编码器精度
	Rotation_Speed_L = encoder_left*Control_Frequency/EncoderMultiples/Reduction_Ratio/Encoder_precision;
	Velocity_Left = Rotation_Speed_L*PI*Diameter_67;    //求出编码器速度=转速*周长
	Rotation_Speed_R = encoder_right*Control_Frequency/EncoderMultiples/Reduction_Ratio/Encoder_precision;
	Velocity_Right = Rotation_Speed_R*PI*Diameter_67;    //求出编码器速度=转速*周长
}

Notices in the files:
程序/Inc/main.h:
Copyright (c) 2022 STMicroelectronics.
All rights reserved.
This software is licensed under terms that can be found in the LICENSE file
